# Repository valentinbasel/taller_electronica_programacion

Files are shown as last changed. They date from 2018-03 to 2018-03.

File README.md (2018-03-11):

# taller_electronica_programacion

taller de programación y diseño de circuitos usando software libre y hardware del proyecto PINGUINO (18F2550)

## introducción

En la actualidad, los sistemas digitales son cada ves mas transversales a nuestra vida cotidiana, sin embargo el nivel de desconocimiento que se tiene sobre los procesos de diseño, fabricación y programación de los dispositivos electrónicos digitales es enorme, casi se podría decir que estamos ante un oscurantismo tecnológico, en el marco de el segundo cercamiento de los bienes comunes (Boyle, 2003). 

Abordar un proyecto de robótica como Recurso Educativo Abierto (REA/OER), implica una serie de desarrollos conceptuales y teóricos que van a más allá del diseño y desarrollo técnico de hardware y software. El uso de REA/OER (Montoya y Aguilar, 2012) implica un compromiso político-epistemológico con respecto al uso de la tecnología, esto es, la apropiación de términos conceptuales como ”software libre”, ”soberanía tecnológica” y cultura libre.

## Taller

Este repositorio esta diseñado para ir desarrollando un taller de electrónica básica, donde abordaremos el diseño de un PCB (Printed circuit board)de simple faz, para la construcción de un circuito basado en el micro controlador 18F2550.

Luego pasaremos a programar el micro controlador mediante las librerías del proyecto PINGUINO-BOARD (usando el software ICARO), viendo formas de programarlo en lenguaje de bloques (icaro-bloques), lenguaje C y controlar la placa (como un datalogger) mediante PYTHON.

## Repositorio 

En este repositorio, vamos a ir almacenando toda la información pertinente para el desarrollo del curso, desde lista de materiales, dinamica de trabajo, archivos KICAD y presentaciones del curso.

## Cronograma

El taller esta dividido en 2 momentos, cada uno de 2 horas (aunque se pueden estirar en función de las necesidades).

### Primer momento

- presentación del taller y los objetivos (diapositiva). 
- Preparación de las notebook que se usaran en el taller (levantar live usb de FEDORA).
- introducción al diseño de pcbs con KICAD.
- impresión y transferencia del PCB para luego atacarlo con cloruro férrico.
- soldadura de los componentes electrónicos y prueba del bootloader V4 de pinguino.

### Segundo momento

- Abordaremos los aspectos del uso de software para cargar un firmware en los micro controladores (usando icaro-bloques)
- comunicación USB-CDC mediante el pic y la PC.
- un taller de programación en PYTHON
- una introducción a los sistemas de visión artificial, usando las librerias open-cv.

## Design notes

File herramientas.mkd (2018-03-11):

# Herramientas

Las herramientas son fundamentales para poder fabricar un pcb, aunque muchas pueden ser remplazadas (en ves de usar un anafe eléctrico, se puede calentar el cloruro con la misma plancha con la que pegamos el dibujo en el PCB) y algunos son de uso común (como el cloruro ferrico y el des soldador), sin embargo, hay herramientas que se recomienda que estén en cada grupo para asi evitar perdidas de tiempo y posibles errores.
Las siguientes listas están divididas en herramientas de uso común y herramientas de cada Kit (herramientas que debería haber por cada kit que se quiera construir):

## Comunes:

- Dremel.
- cloruro ferrico.
- Bandejas para cloruro (bandejas de plastico comunes).
- Bandeja grande para agua (para poner en baño maria la bandeja de cloruro ferrico). 
- Plancha de ropa.
- Mechas 0.75 mm.
- Chupon de estaño.
- Mini destornilladores.
- Multimetro.
- Anafe eléctrico (para calentar el cloruro ferrico).
- Sierra para cortar metal (por si cortamos los pcbs).
- elementos para limpiar la superficie del PCB virgen.
- - Lana de acero.
- - pasta para pulir.
- - guantes de látex (sin esterilizar).
- - alcohol.

## Kit:

- Soldadores de estaño.
- Estaño.
- Alicate de electronica.
- Cables usb de impresora.

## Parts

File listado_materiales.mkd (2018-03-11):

# Materiales

## Kit 

Cada kit  equivale a 1 PCB armado, tiene los elementos necesarios para poder fabricar una placa "pinguino-like". La recomendación es que se trabaje entre 2 y 3 personas por placa.

### Componentes:

- 1 pcb virgenes 10x10cm
- 1 pics 18f2550
- 1 cristales 20 mhz
- 1 conectores usb tipo b
- 1 cap 220 nf
- 2 cap 22 pF
- 1 cap electroliticos 100 uF
- 1 push button (boton de reset)
- 2 leds
- 1 res 1 k
- 1 res 470 ohms
- 1 borneras
- 1 socalos 14x2
- 1 tira de pines macho

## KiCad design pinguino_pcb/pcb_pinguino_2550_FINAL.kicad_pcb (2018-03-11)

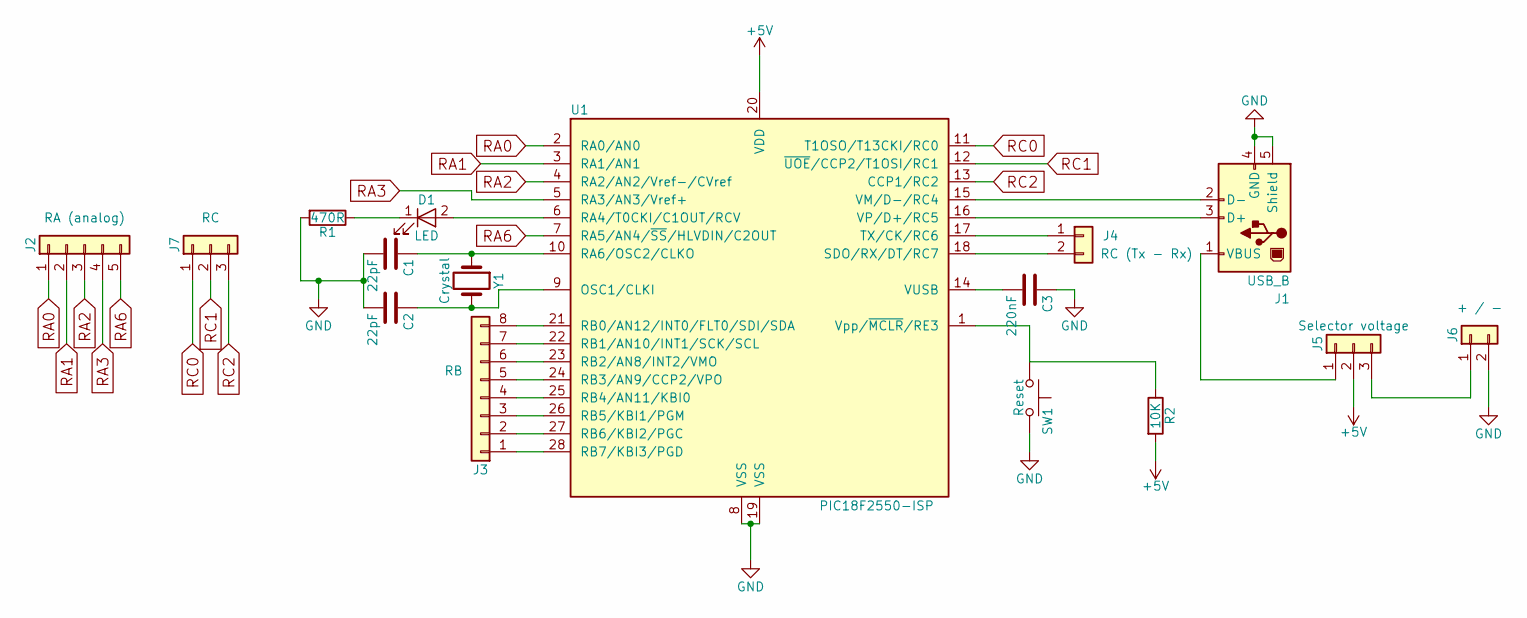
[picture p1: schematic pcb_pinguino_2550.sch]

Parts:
C1, C2: 22pF; C_Disc_D5.0mm_W2.5mm_P5.00mm
C3: 220nF; C_Disc_D5.0mm_W2.5mm_P5.00mm
D1: LED; LED_D5.0mm
J1: USB_B
J2: RA (analog); Pin_Header_Straight_1x05_Pitch2.54mm
J3: RB; Pin_Header_Straight_1x08_Pitch2.54mm
J4: RC (Tx - Rx); Pin_Header_Straight_1x02_Pitch2.54mm
J5: Selector voltage; Pin_Header_Straight_1x03_Pitch2.54mm
J6: + / -; Pin_Header_Straight_1x02_Pitch2.54mm
J7: RC; Pin_Header_Straight_1x03_Pitch2.54mm
R1: 470R; R_Axial_DIN0207_L6.3mm_D2.5mm_P10.16mm_Horizontal
R2: 10K; R_Axial_DIN0207_L6.3mm_D2.5mm_P10.16mm_Horizontal
SW1: Reset; SW_PUSH_6mm_h5mm
U1: PIC18F2550-ISP; DIP-28_W15.24mm_LongPads
Y1: Crystal; Crystal_HC49-U_Vertical

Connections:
+5V: J5.2, R2.2, U1.20 (VDD)
GND: C1.2, C2.2, C3.1, J1.4 (GND), J1.5 (Shield), J6.2, R1.2, SW1.2, U1.8 (VSS), U1.19 (VSS)
unnamed: C1.1, U1.10 (RA6/OSC2/CLKO), Y1.1
unnamed: C2.1, U1.9 (OSC1/CLKI), Y1.2
unnamed: C3.2, U1.14 (VUSB)
unnamed: D1.1 (K), R1.1
unnamed: D1.2 (A), U1.6 (RA4/T0CKI/C1OUT/RCV)
unnamed: J1.1 (VBUS), J5.1
unnamed: J1.2 (D-), U1.15 (VM/D-/RC4)
unnamed: J1.3 (D+), U1.16 (VP/D+/RC5)
unnamed: J3.1, U1.28 (RB7/KBI3/PGD)
unnamed: J3.2, U1.27 (RB6/KBI2/PGC)
unnamed: J3.3, U1.26 (RB5/KBI1/PGM)
unnamed: J3.4, U1.25 (RB4/AN11/KBI0)
unnamed: J3.5, U1.24 (RB3/AN9/CCP2/VPO)
unnamed: J3.6, U1.23 (RB2/AN8/INT2/VMO)
unnamed: J3.7, U1.22 (RB1/AN10/INT1/SCK/SCL)
unnamed: J3.8, U1.21 (RB0/AN12/INT0/FLT0/SDI/SDA)
unnamed: J4.1, U1.17 (TX/CK/RC6)
unnamed: J4.2, U1.18 (SDO/RX/DT/RC7)
unnamed: J5.3, J6.1
unnamed: R2.1, SW1.1, U1.1 (Vpp/~MCLR~/RE3)
RA0: J2.1, U1.2 (RA0/AN0)
RA1: J2.2, U1.3 (RA1/AN1)
RA2: J2.3, U1.4 (RA2/AN2/Vref-/CVref)
RA3: J2.4, U1.5 (RA3/AN3/Vref+)
RA6: J2.5, U1.7 (RA5/AN4/~SS~/HLVDIN/C2OUT)
RC0: J7.1, U1.11 (T1OSO/T13CKI/RC0)
RC1: J7.2, U1.12 (~UOE~/CCP2/T1OSI/RC1)
RC2: J7.3, U1.13 (CCP1/RC2)

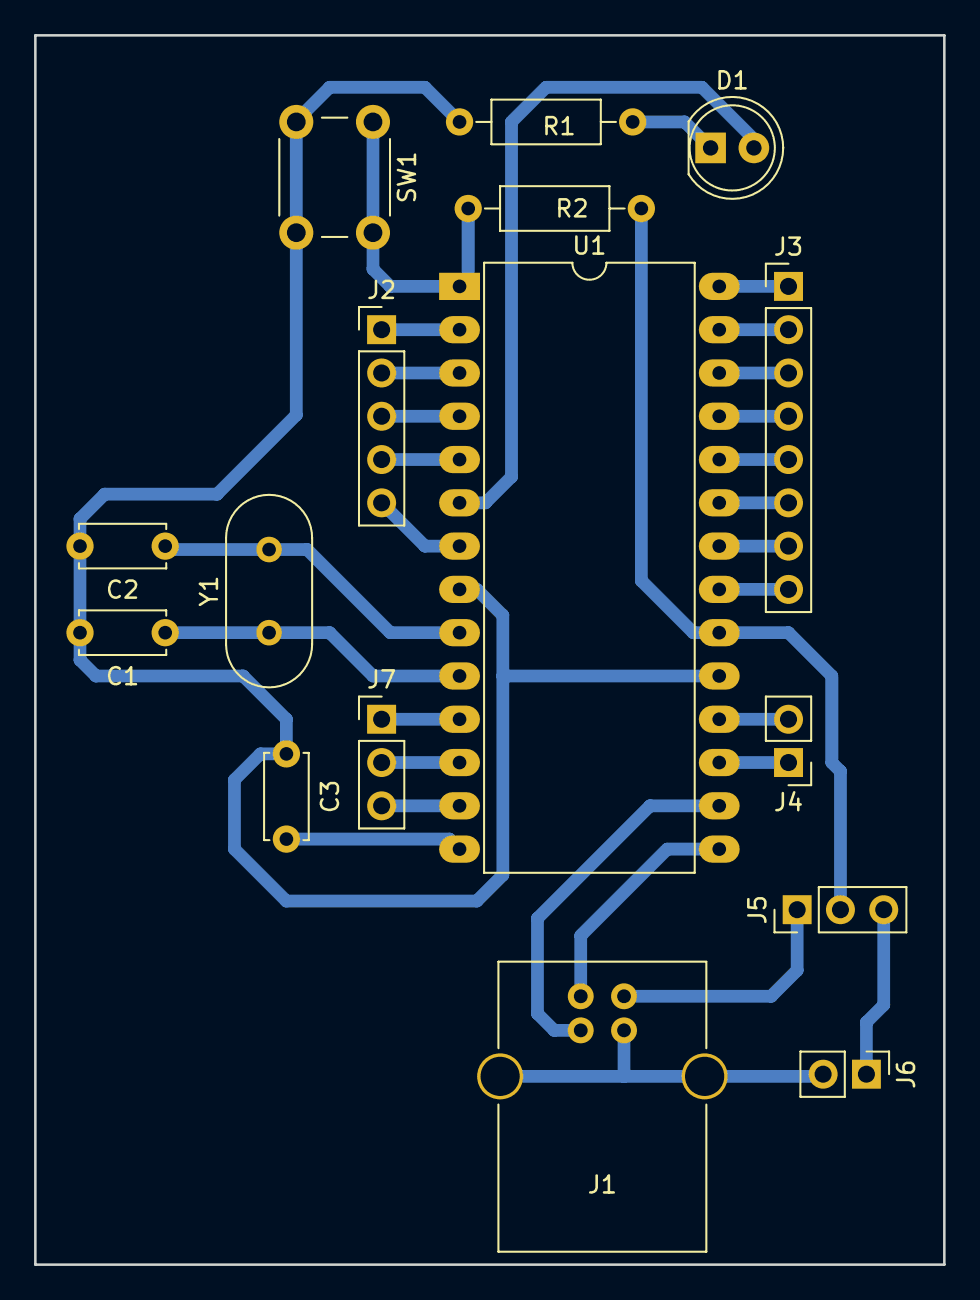
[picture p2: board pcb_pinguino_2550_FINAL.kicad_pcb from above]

Board: 2 copper layers, 53.3 x 72.1 mm, 16 parts (0 on the bottom side), 30 nets.
